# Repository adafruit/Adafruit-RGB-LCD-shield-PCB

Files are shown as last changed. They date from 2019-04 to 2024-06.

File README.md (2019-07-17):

# RGB LCD Shield Kit

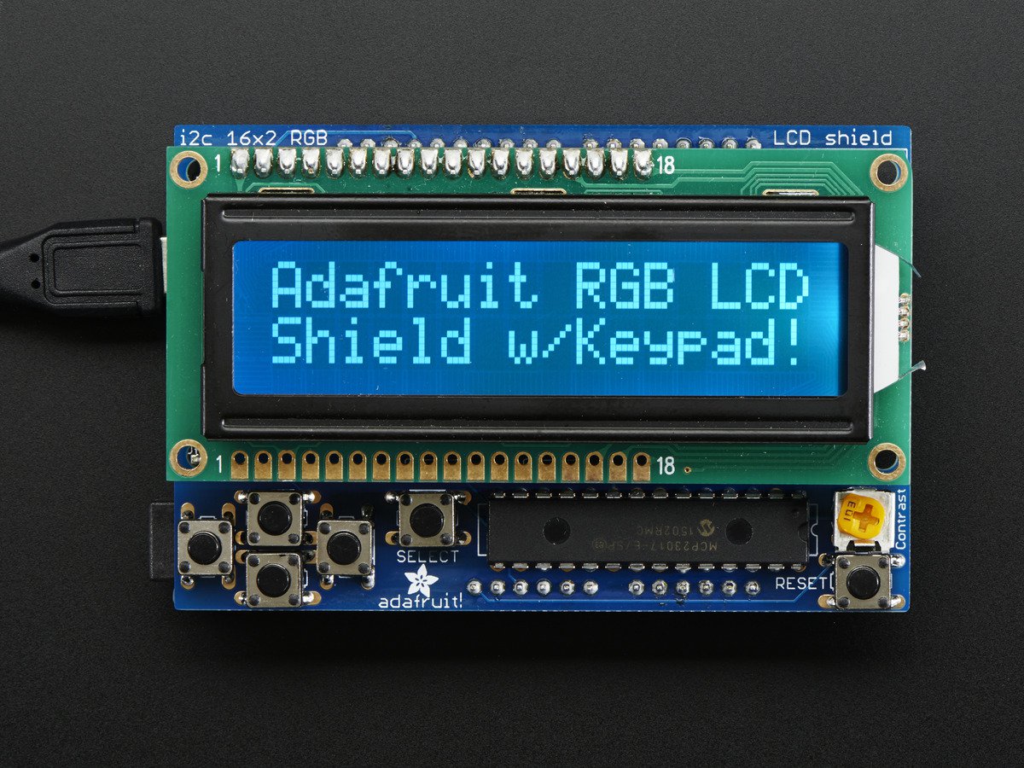
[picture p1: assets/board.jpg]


This new Adafruit shield makes it easy to use a 16x2 Character LCD. We really like the RGB LCDs we stock in the shop both the [RGB negative](http://www.adafruit.com/products/399) and [RGB positive](http://www.adafruit.com/products/398). Unfortunately, these LCDs do require quite a few digital pins, 6 to control the LCD and then another 3 to control the RGB backlight for a total of 9 pins. That's half of the pins available on a classic Arduino!

With this in mind, we wanted to make it easier for people to get these LCD into their projects so we devised a shield that lets you control __a 16x2 Character LCD, up to 3 backlight pins AND 5 keypad pins using only the two I2C pins on the Arduino!__ The best part is you don't really lose those two pins either, since you can stick i2c-based sensors, RTCs, etc and have them share the I2C bus. This is a super slick way to add a display without all the wiring hassle.

This shield is perfect for when you want to build a stand-alone project with its own user interface. The 4 directional buttons plus select button allows basic control without having to attach a bulky computer.

The shield is designed for 'classic' Arduinos such as the Uno, Duemilanove, Diecimilla, etc. It uses the I2C pins at Analog 4 and Analog 5. It will also work perfectly with Arduino Mega R3's which have the extra SDA/SCL I2C pins broken out. Earlier Mega's have the I2C pins in a different location and will require you to solder two wires from the I2C pins on the shield and plug them into the different I2C locations at Digital 20 & 21. This shield will not fit easily on top of an Arduino Ethernet because of the Ethernet jack height. [You can use a set of stacking headers to give the shield more 'lift' above the jack](http://www.adafruit.com/products/85).

__This product comes as a kit!__ Included is a high quality, USA-made PCB and all the components (buttons, header etc). This product comes with a [16x2 RGB negative](http://www.adafruit.com/products/399). Assembly is easy, even if you've never soldered before and the kit can be completed in 30 minutes. [Check the product tutorial page for assembly instructions before purchasing](http://learn.adafruit.com/rgb-lcd-shield).

### License

Adafruit invests time and resources providing this open source design, please support Adafruit and open-source hardware by purchasing products from [Adafruit](https://www.adafruit.com)!

Designed by Limor Fried/Ladyada for Adafruit Industries.

Creative Commons Attribution/Share-Alike, all text above must be included in any redistribution. See license.txt for additional details.

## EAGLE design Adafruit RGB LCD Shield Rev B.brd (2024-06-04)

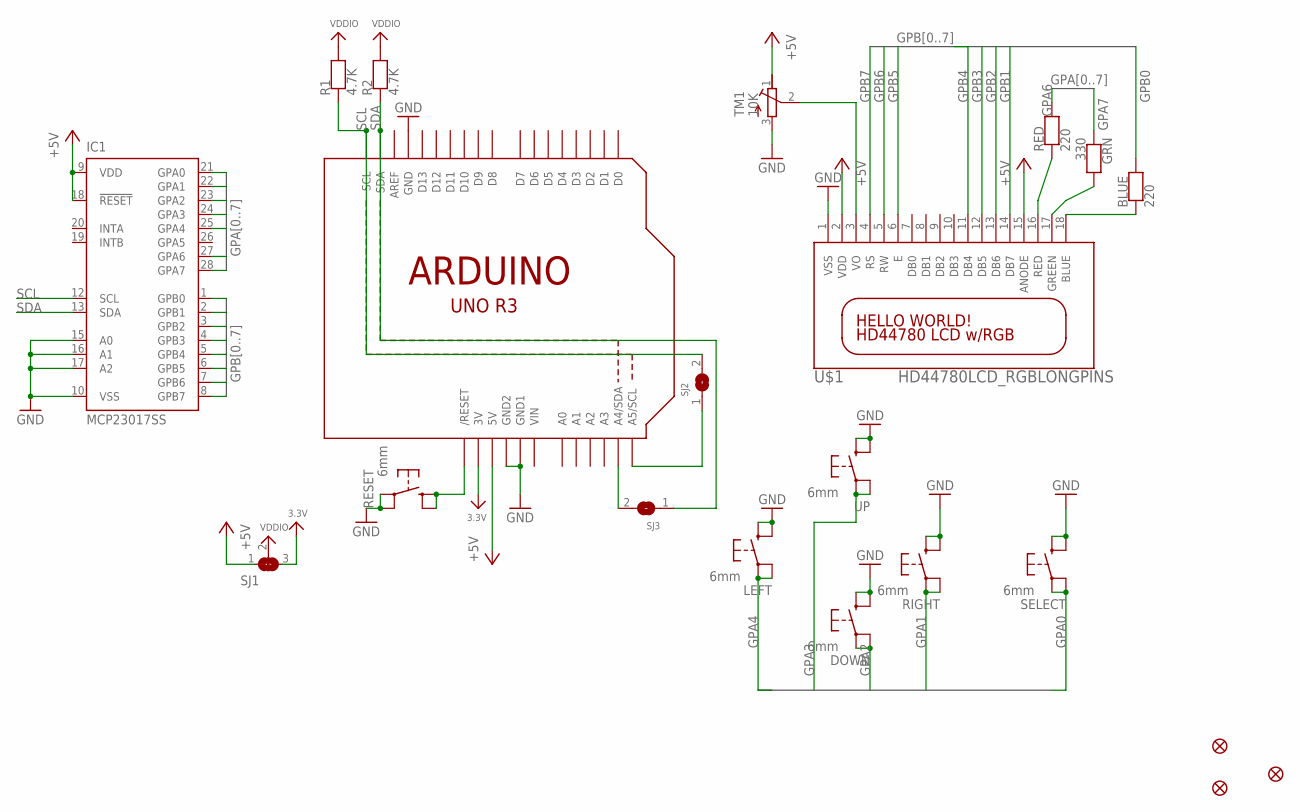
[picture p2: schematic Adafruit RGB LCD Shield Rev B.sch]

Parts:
BLUE: 220; 0805-NO
DOWN: 6mm; 6MMX6MM_TACTILE_SMT
FID1, FID2, FID3: FIDUCIAL_1MM
GRN: 330; 0805-NO
IC1: MCP23017SS; SSOP28
LEFT: 6mm; 6MMX6MM_TACTILE_SMT
R1, R2: 4.7K; 0805-NO
RED: 220; 0805-NO
RESET: 6mm; 6MMX6MM_TACTILE_SMT
RIGHT: 6mm; 6MMX6MM_TACTILE_SMT
SELECT: 6mm; 6MMX6MM_TACTILE_SMT
SJ1: SOLDERJUMPER_2WAY; SOLDERJUMPER_2WAY_OPEN_NOPASTE
SJ2, SJ3: SOLDERJUMPER; SOLDERJUMPER_ARROW_NOPASTE
TM1: 10K; RTRIM3314J
U1: ARDUINOR3-NOIOREF-NOTEXT; ARDUINOR3-NOTEXT-NOIOREF
U$1: HD44780LCD_RGBLONGPINS; LCD1602-RGB
UP: 6mm; 6MMX6MM_TACTILE_SMT

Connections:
3.3V: SJ1.3, U1.3V
+5V: IC1.9 (VDD), IC1.18 (!RESET), SJ1.1, TM1.1 (E), U1.5V, U$1.2 (VDD), U$1.15 (ANODE)
GND: DOWN.B (S), DOWN.B' (S1), IC1.10 (VSS), IC1.15 (A0), IC1.16 (A1), IC1.17 (A2), LEFT.B (S), LEFT.B' (S1), RESET.A, RESET.A' (P1), RIGHT.B (S), RIGHT.B' (S1), SELECT.B (S), SELECT.B' (S1), TM1.3 (A), U1.GND, U1.GND1, U1.GND2, U$1.1 (VSS), UP.B (S), UP.B' (S1)
GPA0: IC1.21 (GPA0), SELECT.A, SELECT.A' (P1)
GPA1: IC1.22 (GPA1), RIGHT.A, RIGHT.A' (P1)
GPA2: DOWN.A, DOWN.A' (P1), IC1.23 (GPA2)
GPA3: IC1.24 (GPA3), UP.A, UP.A' (P1)
GPA4: IC1.25 (GPA4), LEFT.A, LEFT.A' (P1)
GPA6: IC1.27 (GPA6), RED.2
GPA7: GRN.1, IC1.28 (GPA7)
GPB0: BLUE.2, IC1.1 (GPB0)
GPB1: IC1.2 (GPB1), U$1.14 (DB7)
GPB2: IC1.3 (GPB2), U$1.13 (DB6)
GPB3: IC1.4 (GPB3), U$1.12 (DB5)
GPB4: IC1.5 (GPB4), U$1.11 (DB4)
GPB5: IC1.6 (GPB5), U$1.6 (E)
GPB6: IC1.7 (GPB6), U$1.5 (RW)
GPB7: IC1.8 (GPB7), U$1.4 (RS)
unnamed: BLUE.1, U$1.18 (BLUE)
unnamed: GRN.2, U$1.17 (GREEN)
unnamed: RED.1, U$1.16 (RED)
unnamed: TM1.2 (S), U$1.3 (VO)
unnamed: SJ3.2, U1.A4 (A4/SDA)
unnamed: SJ2.1, U1.A5 (A5/SCL)
RESET: RESET.B (S), RESET.B' (S1), U1.RESET (/RESET)
SCL: IC1.12 (SCL), R1.1, SJ2.2, U1.SCL
SDA: IC1.13 (SDA), R2.1, SJ3.1, U1.SDA
VDDIO: R1.2, R2.2, SJ1.2
VIN: U1.VIN

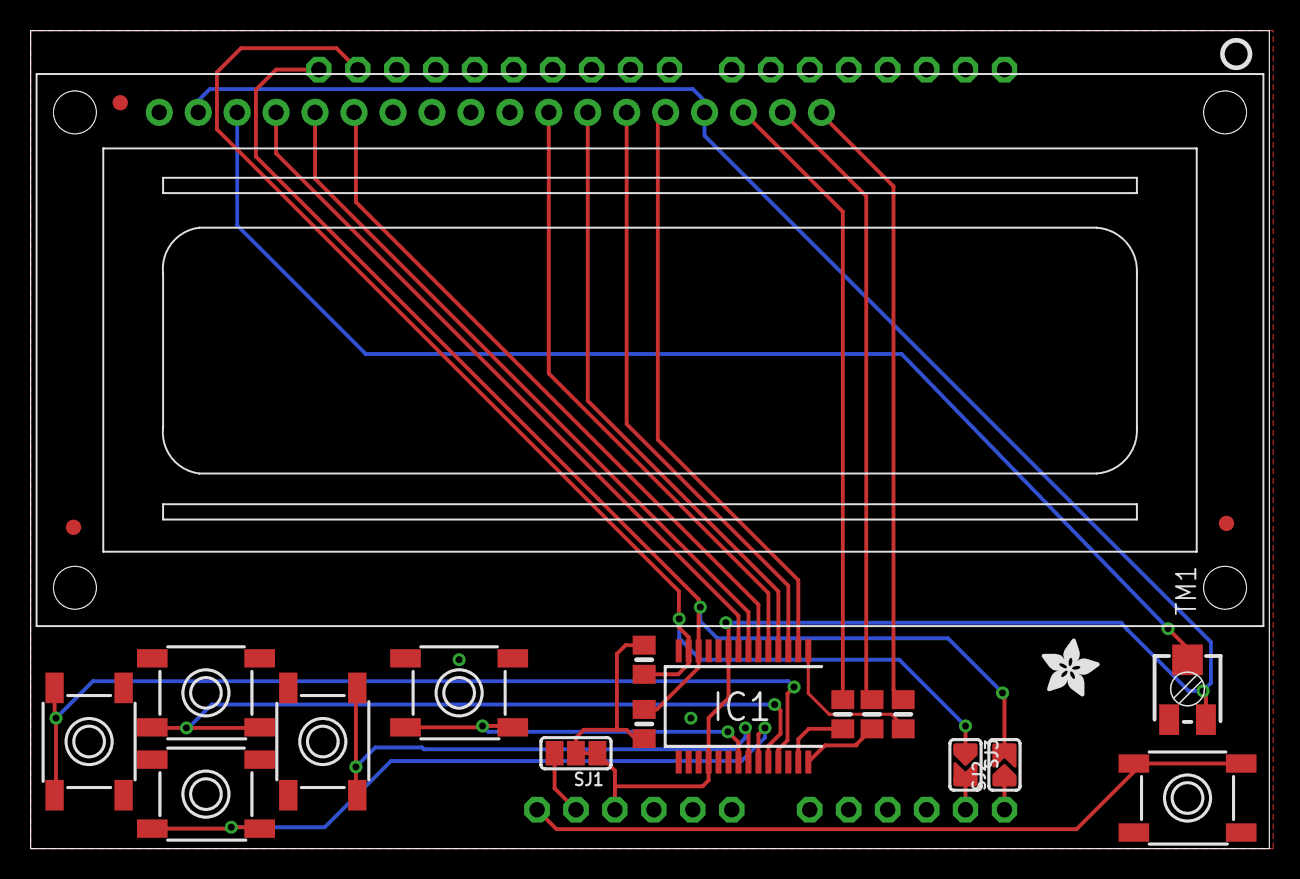
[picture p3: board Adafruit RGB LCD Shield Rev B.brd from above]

Board: 2 copper layers, 80.8 x 53.3 mm, 38 parts (0 on the bottom side), 28 nets.

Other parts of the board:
E$1: PCBFEAT-REV-040
PLABEL1: PLABEL1
PLABEL2: PLABEL2
PLABEL3: PLABEL3
PLABEL4: PLABEL4
PLABEL5: PLABEL5
PLABEL6: PLABEL6
PLABEL7: PLABEL7
PLABEL8: PLABEL8
PLABEL9: PLABEL9
PLABEL10: PLABEL10
PLABEL11: PLABEL11
PLABEL12: PLABEL12
PLABEL13: PLABEL13
PLABEL14: PLABEL14
PLABEL15: PLABEL15
U$4: ADAFRUIT_3.5MM

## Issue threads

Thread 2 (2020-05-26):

Pushbutton + circuit python Problem

kj1k, 2020-05-26:
Used the demo code for the display successfully, then used Tony D's mcp23017 code to write a simple circuit python script to detect pushbuttons.  After executing the pushbutton script the display froze and cannot be cleared.
[mcp23017_py.txt](https://github.com/adafruit/Adafruit-RGB-LCD-shield-PCB/files/4683327/mcp23017_py.txt)
[piplate_demo_py.txt](https://github.com/adafruit/Adafruit-RGB-LCD-shield-PCB/files/4683352/piplate_demo_py.txt)

kj1k, 2020-05-26:
OOps!  it was my fault.   I was running a program that used the display when I started another program to check the pushbuttons.   Since the display uses the same i2c address as the mcp23017, the display microcomputer obviously got confused.

Fortunately I can get replacement "new" units from ebay (adafruit is out of stock)

I will merge the two programs so I will not make the mistake again.

Closed 2020-05-26.

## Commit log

2011-12-25 layed out, lets make it!
    [rgblcdshield.brd, rgblcdshield.sch]
2011-12-25 shifted chip to the right
    [rgblcdshield.brd, rgblcdshield.sch]
2012-02-15 silk tweaks
    [rgblcdshield.brd, rgblcdshield.sch]
2012-02-15 skootched the schematic
    [rgblcdshield.sch]
2024-03-14 Update Schematic and board
    [adafruit_rgblcdshield.brd, adafruit_rgblcdshield.sch]
2024-06-04 adding rev B files
    [Adafruit RGB LCD Shield Rev B.brd, Adafruit RGB LCD Shield Rev B.sch]

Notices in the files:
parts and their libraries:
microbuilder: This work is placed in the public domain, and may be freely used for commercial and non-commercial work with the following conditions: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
